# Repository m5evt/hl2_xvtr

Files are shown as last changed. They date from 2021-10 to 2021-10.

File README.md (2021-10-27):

# hl2_xvtr
hl2_xvtr

Hermes-Lite 2 transverter companion card

Designed with the same footprint as the N2ADR filter board, this companion card is to be coupled to the Hermes-Lite 2 SDR transceiver. The transverter clock is designed to be sourced from the HL2 clock outputs. Power output is around 20 dBm and an amplifier will need to be used with this. 

The design has been built and tested on both 6m and 2m.

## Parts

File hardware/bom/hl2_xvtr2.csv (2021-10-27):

ID | Value | Footprint | Quantity | Source
C25, C31 | 10uF | CP_Elec_5x5.4 | 2 | Mouser: 598-106SML035M
C8, C14, C42 | 100p | SMD-0603 | 3
C4, C10, C12, C13, C15, C17, C19, C22, C32, C33, C34, C47, C50 | 1n | SMD-0603_c | 13
C21, C30, | 3.3p | SMD-0603_c | 2
C38, C45 | 2.7p | SMD-0603_c | 2
C23, C29, | 4.7p | SMD-0603_c | 2
C41, C48 | 5.6p | SMD-0603_c | 2
C2, C5, C35 | 82p | SMD-0603_c | 3
C6, C36, C37 | 510p | SMD-0603_c | 3
C20, C49, C51 | 1u | SMD-0603_c | 3
C24, C28, C43 | 0.5p | SMD-0603_c | 3
C1, C7 | 68p | SMD-0603_c | 2
C9, C11 | 150p | SMD-0603_c | 2
C16, C18 | 47p | SMD-0603_c | 2
C3 | 560p | SMD-0603_c | 1
C26 | 7.5p | SMD-0603_c | 1
C27 | DNF | SMD-0603_c | 1
C39 | 10p | SMD-0603_c | 1
C40 | 1.2p | SMD-0603_c | 1
C44 | 3.3p | SMD-0603_c | 1
C46 | 8.2p | SMD-0603_c | 1
R13, R15, R41, R42 | 390R | SMD-0603_r | 4
R11, R36, R40 | 1k | SMD-0603_r | 3
R9, R12 | 10k | SMD-0603_r | 2
R8 | 0R | SMD-0603_r | 1
R10 | 470R | SMD-0603_r | 1
R37 | 47R | SMD-0603_r | 1
R38 | 220k | SMD-0603_r | 1
R43 | 10R | SMD-0603_r | 1
R1, R3 | 150R | SMD-0805 | 2
R2 | 38R | SMD-0805 | 1
L1, L7, L15, L16 | 470nH | SMD-0805 | 4 | Mouser: 994-0805HP-471XGRC
L2, L3, L5 | 270nH | SMD-0805 | 3 | Mouser: 994-0805HP-271XGRB
L4, L8 | 1uH | SMD-0805 | 2 | Mouser: 994-0805AF-102XJRB
L6, L9 | 220nH | SMD-0805 | 2 | Mouser: 994-0805HP-221XGRC
L18, L22 | 68nH | SMD-0805 | 2 | Mouser: 652-CW201212-68NJ
L10, L11, L12, L17, L21 | 150nH | coilcraft_tunable_coil | 5 | Mouser: 994-150-04J08L
D2, D8 | 1N4148W | D_SOD-123 | 2 | Mouser: 621-1N4148W-F
D1, D3 | BAP64 | SOT23_3 | 2 | Mouser: 771-BAP64-05-T/R
U2 | ADE-1H+ | Mini-Circuits_CD542_LandPatternPL-052 | 1 | Mouser: 139-ADE-1H
U5 | 74LVC1G04 | SOT-353_SC-70-5_Handsoldering | 1 | Mouser: 621-74LVC1G04SE-7
U1, U7 | PGA-105 | SOT-89-3_round | 2 | Mouser: 139-PGA-105
U3, U4 | SPF5189Z | SOT-89-3_round | 2 | Mouser: 772-SPF5189Z
U6 | 7805 | TO-263-2 | 1 | Mouser: 863-MC7805CD2TG
Q6, Q7 | SI2309 | SOT-23 | 2 | Mouser: 781-SI2309CDS-GE3
Q5 | BC807 | SOT-23 | 1 | Mouser: 583-BC807
J2, J3, J4, J5 | Conn_Coaxial-Connector | BNCEDGE | 4 | DNF
J10 | RCJ-041 | PhonoRcaRCJ-04x | 1 | MOUSER: 490-RCJ-041
J6 | Conn_01x20 | PinSocket_1x20_P2.54mm_Vertical | 1
J1 | Conn_Coaxial-Connector | U.FL_Hirose_U.FL-R-SMT-1_Vertical | 1 | Mouser: 712-CONUFL001-SMD-T
P1 | CONN_01X03 | PinSocket_1x03_P2.54mm_Vertical | 1

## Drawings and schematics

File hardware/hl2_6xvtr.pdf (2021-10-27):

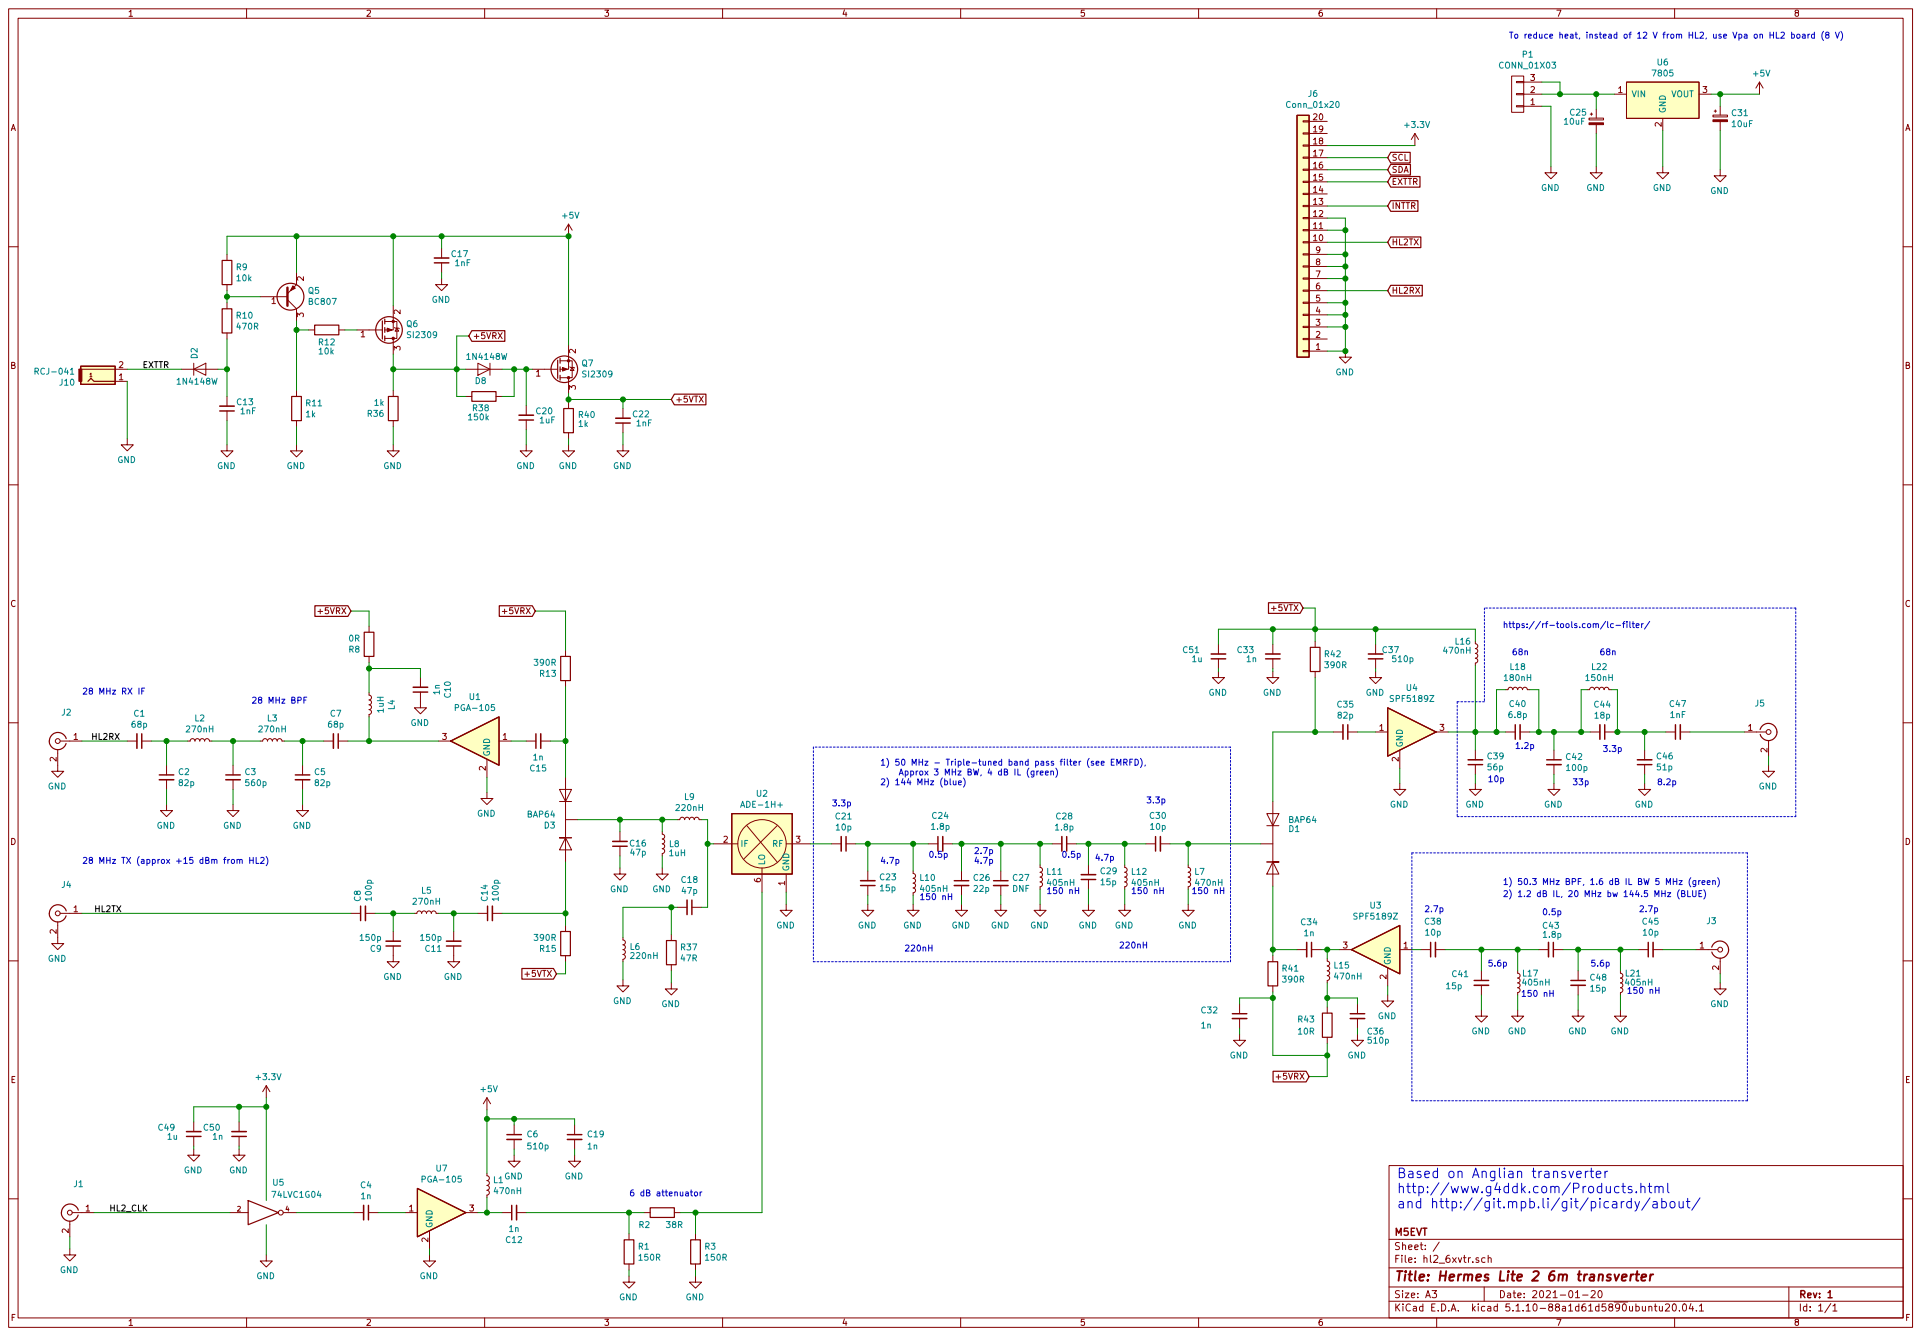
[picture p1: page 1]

To reduce heat, instead of 12 V from HL2, use Vpa on HL2 board (8 V)
J6 Conn_01x20 C51

https://rf-tools.com/lc-filter/

1) 50.3 MHz BPF, 1.6 dB IL BW 5 MHz (green) 28 MHz RX IF

1) 50 MHz - Triple-tuned band pass filter (see EMRFD),
Approx 3 MHz BW, 4 dB IL (green)
2) 144 MHz (blue)

28 MHz TX (approx +15 dBm from HL2)

2) 1.2 dB IL, 20 MHz bw 144.5 MHz (BLUE)

and http://git.mpb.li/git/picardy/about/ 150 nH

Based on Anglian transverter
http://www.g4ddk.com/Products.html

Id: 1/1 Title: Hermes Lite 2 6m transverter

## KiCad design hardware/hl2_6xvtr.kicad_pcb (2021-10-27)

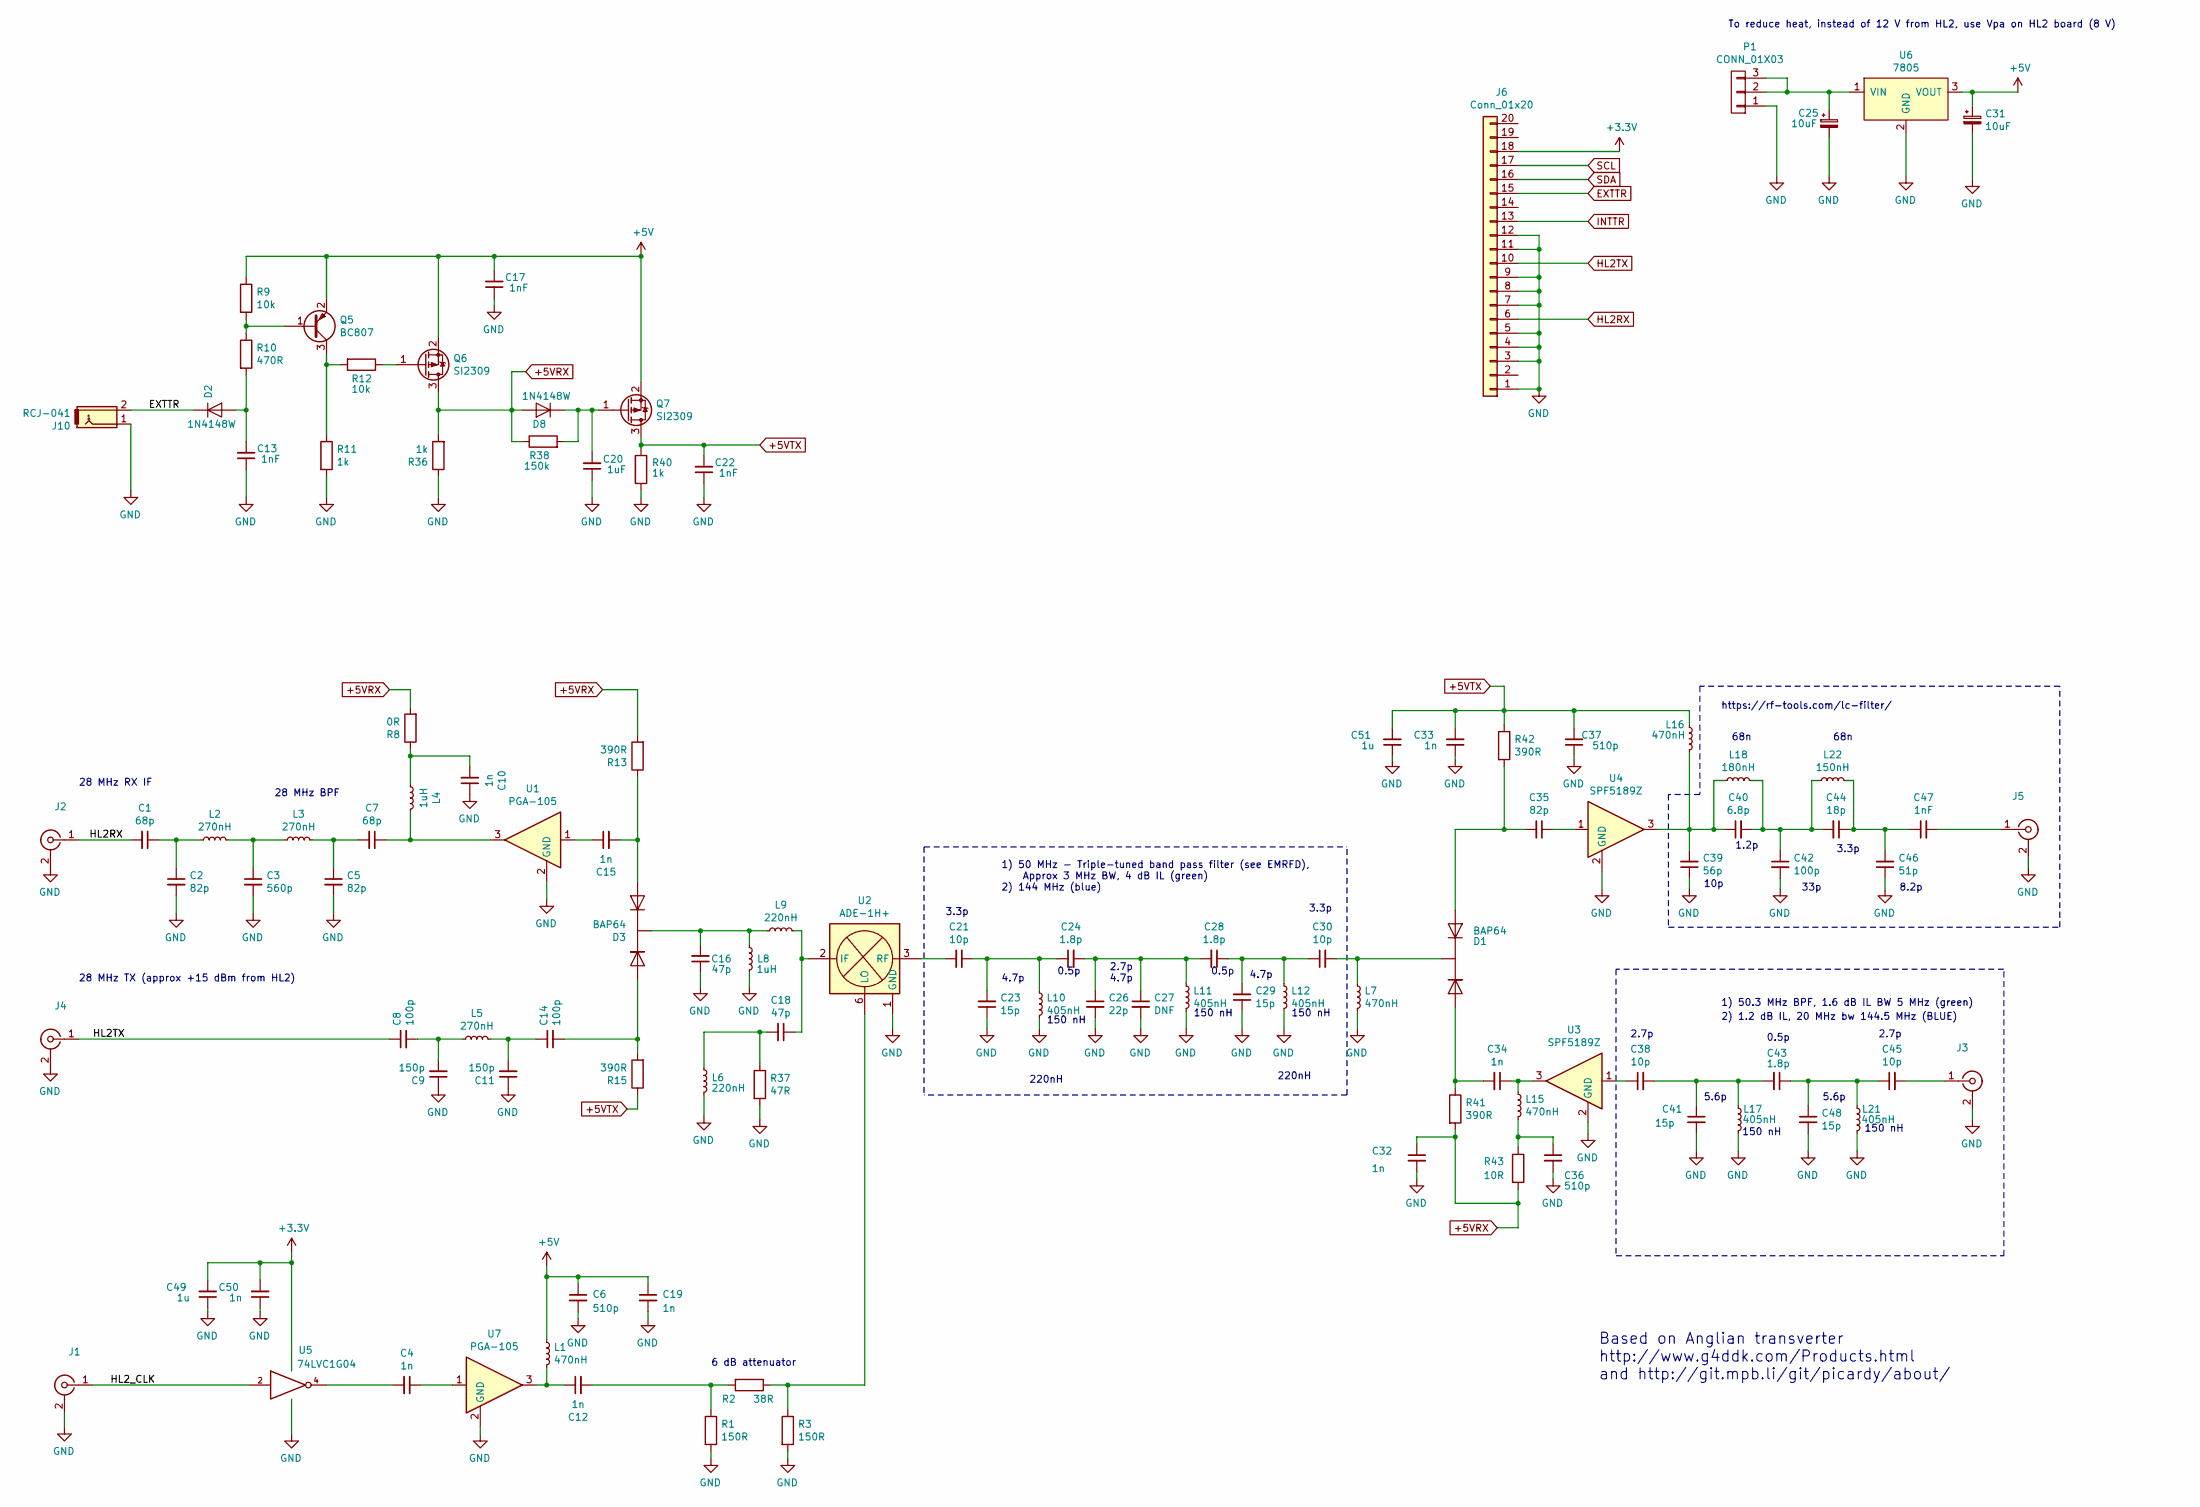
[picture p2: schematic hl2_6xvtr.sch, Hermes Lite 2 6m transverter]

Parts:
C1, C7: 68p; SMD-0603_c
C2, C5, C35: 82p; SMD-0603_c
C3: 560p; SMD-0603_c
C4, C10, C12, C15, C19, C32, C33, C34, C50: 1n; SMD-0603_c
C6, C36, C37: 510p; SMD-0603_c
C8, C14, C42: 100p; SMD-0603
C9, C11: 150p; SMD-0603_c
C13, C17, C22, C47: 1nF; SMD-0603_c
C16, C18: 47p; SMD-0603_c
C20: 1uF; SMD-0603_c
C21, C30, C38, C45: 10p; SMD-0603_c
C23, C29, C41, C48: 15p; SMD-0603_c
C24, C28, C43: 1.8p; SMD-0603_c
C25, C31: 10uF; CP_Elec_5x5.4
C26: 22p; SMD-0603_c
C27: DNF; SMD-0603_c
C39: 56p; SMD-0603_c
C40: 6.8p; SMD-0603_c
C44: 18p; SMD-0603_c
C46: 51p; SMD-0603_c
C49, C51: 1u; SMD-0603_c
D1, D3: BAP64; SOT23_3
D2, D8: 1N4148W; D_SOD-123
J1: Conn_Coaxial-Connector; U.FL_Hirose_U.FL-R-SMT-1_Vertical
J2, J3, J4, J5: Conn_Coaxial-Connector; BNCEDGE
J6: Conn_01x20; PinSocket_1x20_P2.54mm_Vertical
J10: RCJ-041; PhonoRcaRCJ-04x
L1, L7, L15, L16: 470nH; SMD-0805
L2, L3, L5: 270nH; SMD-0805
L4, L8: 1uH; SMD-0805
L6, L9: 220nH; SMD-0805
L10, L11, L12, L17, L21: 405nH; coilcraft_tunable_coil
L18: 180nH; SMD-0805
L22: 150nH; SMD-0805
P1: CONN_01X03; PinSocket_1x03_P2.54mm_Vertical
Q5: BC807; SOT-23
Q6, Q7: SI2309; SOT-23
R1, R3: 150R; SMD-0805
R2: 38R; SMD-0805
R8: 0R; SMD-0603_r
R9, R12: 10k; SMD-0603_r
R10: 470R; SMD-0603_r
R11, R36, R40: 1k; SMD-0603_r
R13, R15, R41, R42: 390R; SMD-0603_r
R37: 47R; SMD-0603_r
R38: 150k; SMD-0603_r
R43: 10R; SMD-0603_r
U1, U7: PGA-105; SOT-89-3_round
U2: ADE-1H+; Mini-Circuits_CD542_LandPatternPL-052
U3, U4: SPF5189Z; SOT-89-3_round
U5: 74LVC1G04; SOT-353_SC-70-5_Handsoldering
U6: 7805; TO-263-2

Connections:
+3V3: C49.2, C50.2, J6.18, U5.5 (VCC)
+5V: C6.1, C17.2, C19.1, C31.1, L1.1, Q5.2 (E), Q6.2 (S), Q7.2 (S), R9.1, U6.3 (VOUT)
+5VRX: C32.1, D8.2 (A), Q6.3 (D), R8.2, R13.2, R36.2, R38.1, R41.2, R43.2
+5VTX: C22.2, C33.2, C37.2, C51.2, L16.1, Q7.3 (D), R15.1, R40.1, R42.1
/HL2_CLK: J1.1 (In), U5.2
EXTTR: D2.1 (K), J6.15, J10.2
GND: C2.2, C3.2, C5.2, C6.2, C9.1, C10.1, C11.1, C13.1, C16.1, C17.1, C19.2, C20.1, C22.1, C23.1, C25.2, C26.2, C27.2, C29.1, C31.2, C32.2, C33.1, C36.2, C37.1, C39.1, C41.2, C42.2, C46.1, C48.2, C49.1, C50.1, C51.1, J1.2 (Ext), J2.2 (Ext), J3.2 (Ext), J4.2 (Ext), J5.2 (Ext), J6.1, J6.3, J6.4, J6.5, J6.7, J6.8, J6.9, J6.11, J6.12, J10.1, L6.2, L7.2, L8.2, L10.2, L11.2, L12.2, L17.1, L21.1, P1.1, R1.2, R3.2, R11.2, R36.1, R37.2, R40.2, U1.2 (GND), U2.1 (GND), U2.4 (GND), U2.5 (GND), U3.2 (GND), U4.2 (GND), U5.3 (GND), U6.2 (GND), U7.2 (GND)
HL2RX: C1.2, J2.1 (In), J6.6
HL2TX: C8.1, J4.1 (In), J6.10
INTTR: J6.13
unnamed: C1.1, C2.1, L2.1
unnamed: C3.1, L2.2, L3.1
unnamed: C4.1, U7.1
unnamed: C4.2, U5.4
unnamed: C5.1, C7.2, L3.2
unnamed: C7.1, L4.2, U1.3
unnamed: C8.2, C9.2, L5.1
unnamed: C10.2, L4.1, R8.1
unnamed: C11.2, C14.1, L5.2
unnamed: C12.1, L1.2, U7.3
unnamed: C12.2, R1.1, R2.2
unnamed: C13.2, D2.2 (A), R10.2
unnamed: C14.2, D3.1 (A), R15.2
unnamed: C15.1, U1.1
unnamed: C15.2, D3.2 (A), R13.1
unnamed: C16.2, D3.3 (K), L8.1, L9.1
unnamed: C18.1, L9.2, U2.2 (IF)
unnamed: C18.2, L6.1, R37.1
unnamed: C20.2, D8.1 (K), Q7.1 (G), R38.2
unnamed: C21.1, C23.2, C24.1, L10.1
unnamed: C21.2, U2.3 (RF)
unnamed: C24.2, C26.1, C27.1, C28.2, L11.1
unnamed: C25.1, P1.2, P1.3, U6.1 (VIN)
unnamed: C28.1, C29.2, C30.1, L12.1
unnamed: C30.2, D1.3 (K), L7.1
unnamed: C34.1, L15.1, U3.3
unnamed: C34.2, D1.1 (A), R41.1
unnamed: C35.1, U4.1
unnamed: C35.2, D1.2 (A), R42.2
unnamed: C36.1, L15.2, R43.1
unnamed: C38.1, U3.1
unnamed: C38.2, C41.1, C43.2, L17.2
unnamed: C39.2, C40.1, L16.2, L18.1, U4.3
unnamed: C40.2, C42.1, C44.2, L18.2, L22.1
unnamed: C43.1, C45.1, C48.1, L21.2
unnamed: C44.1, C46.2, C47.1, L22.2
unnamed: C45.2, J3.1 (In)
unnamed: C47.2, J5.1 (In)
unnamed: Q5.1 (B), R9.2, R10.1
unnamed: Q5.3 (C), R11.1, R12.2
unnamed: Q6.1 (G), R12.1
unnamed: R2.1, R3.1, U2.6 (LO)
SCL: J6.17
SDA: J6.16

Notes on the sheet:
Based on Anglian transverter http://www.g4ddk.com/Products.html and http://git.mpb.li/git/picardy/about/
28 MHz RX IF
28 MHz TX (approx +15 dBm from HL2)
1) 50.3 MHz BPF, 1.6 dB IL BW 5 MHz (green)
28 MHz BPF
1) 50 MHz - Triple-tuned band pass filter (see EMRFD), Approx 3 MHz BW, 4 dB IL (green) 2) 144 MHz (blue)
https://rf-tools.com/lc-filter/
To reduce heat, instead of 12 V from HL2, use Vpa on HL2 board (8 V)
6 dB attenuator
2.7p
5.6p
0.5p
150 nH
10p
33p
8.2p
3.3p
1.2p
68n
2) 1.2 dB IL, 20 MHz bw 144.5 MHz (BLUE)
2.7p 4.7p
4.7p
220nH

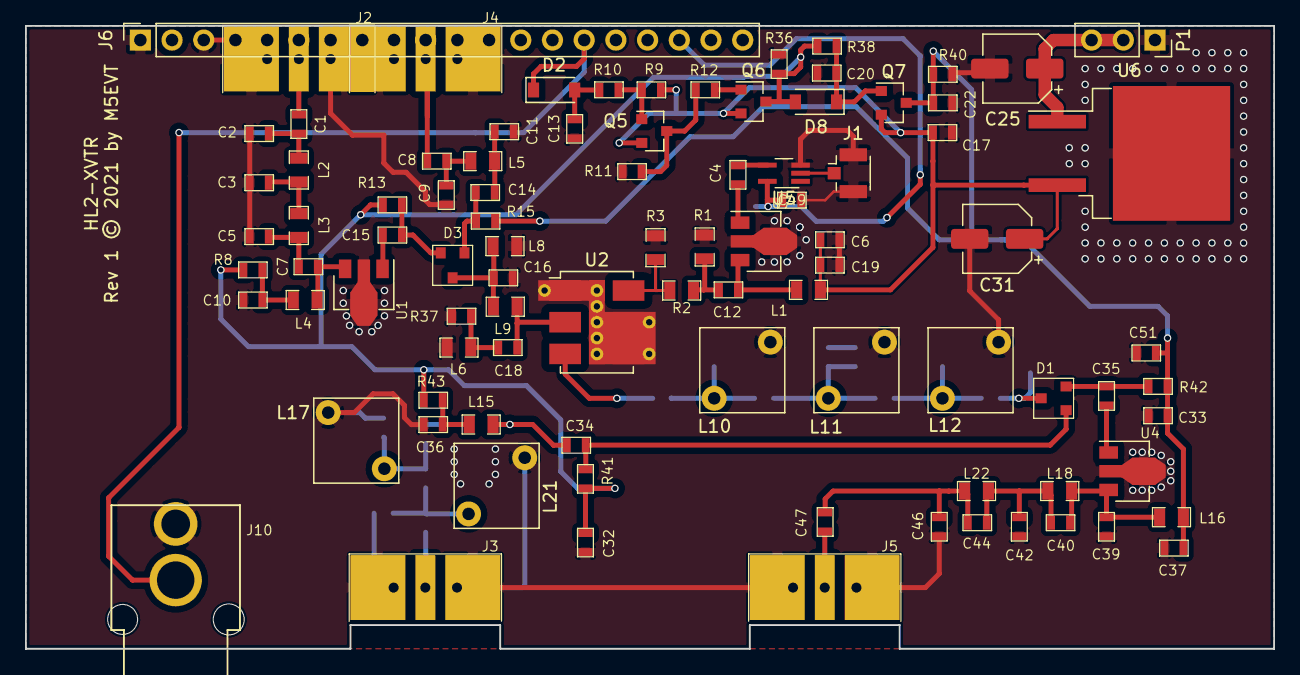
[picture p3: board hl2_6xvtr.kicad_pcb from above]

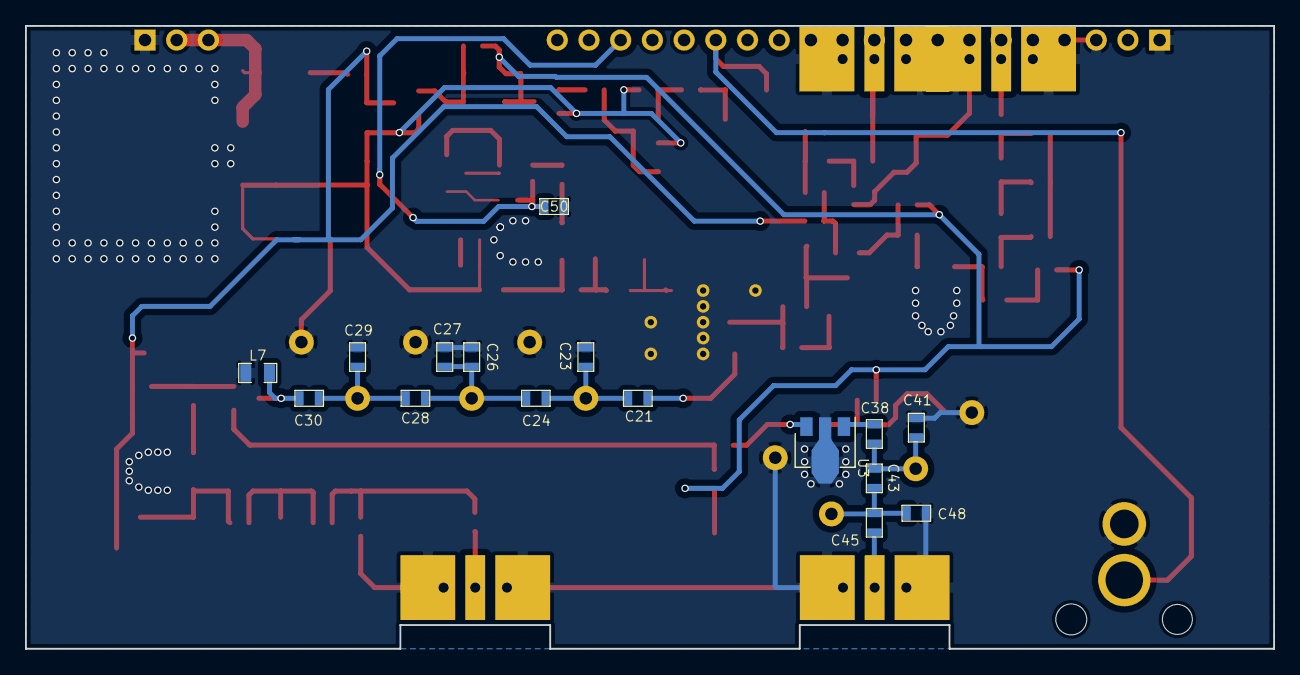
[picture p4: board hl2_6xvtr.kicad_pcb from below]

Board: 2 copper layers, 100.0 x 49.9 mm, 108 parts (16 on the bottom side), 51 nets.

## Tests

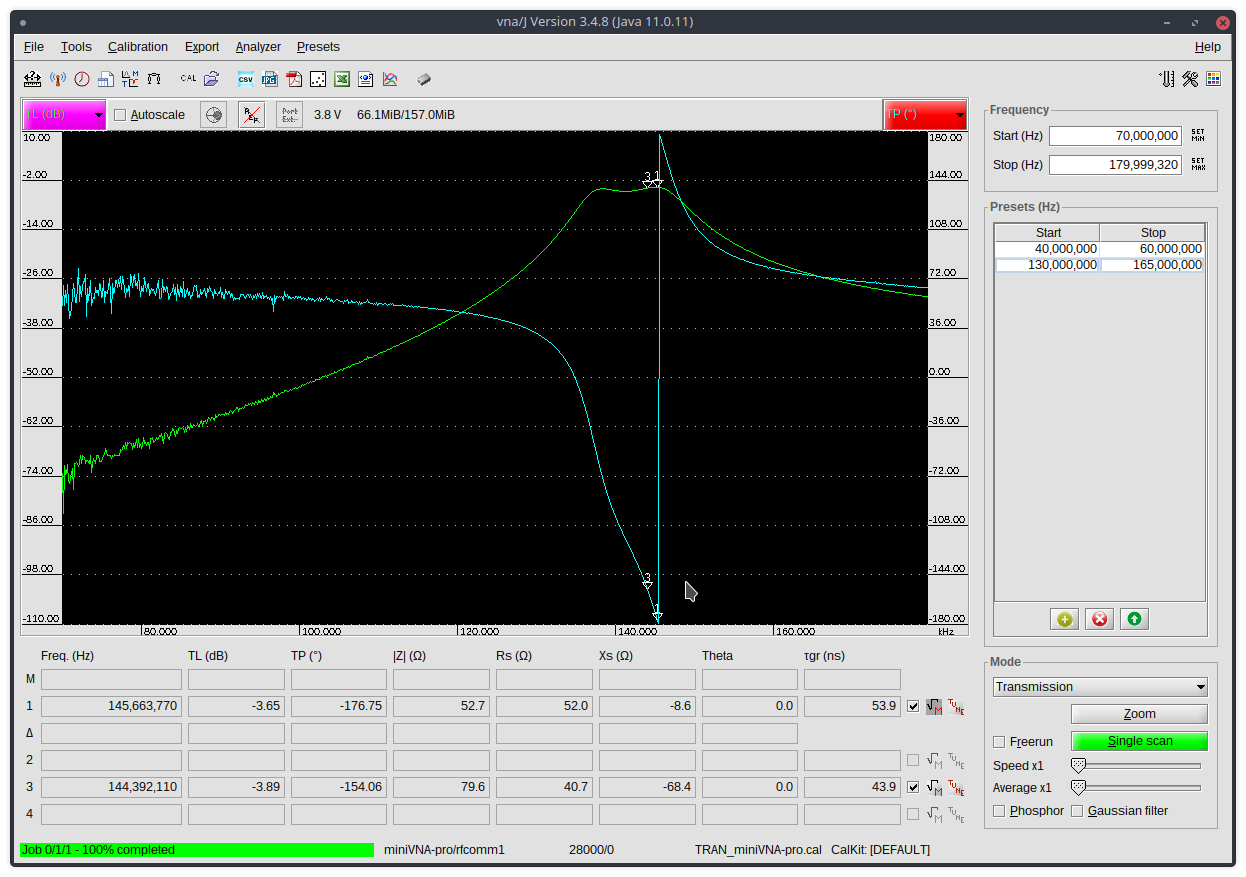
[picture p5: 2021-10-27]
measurements/2m_input_bpf.png

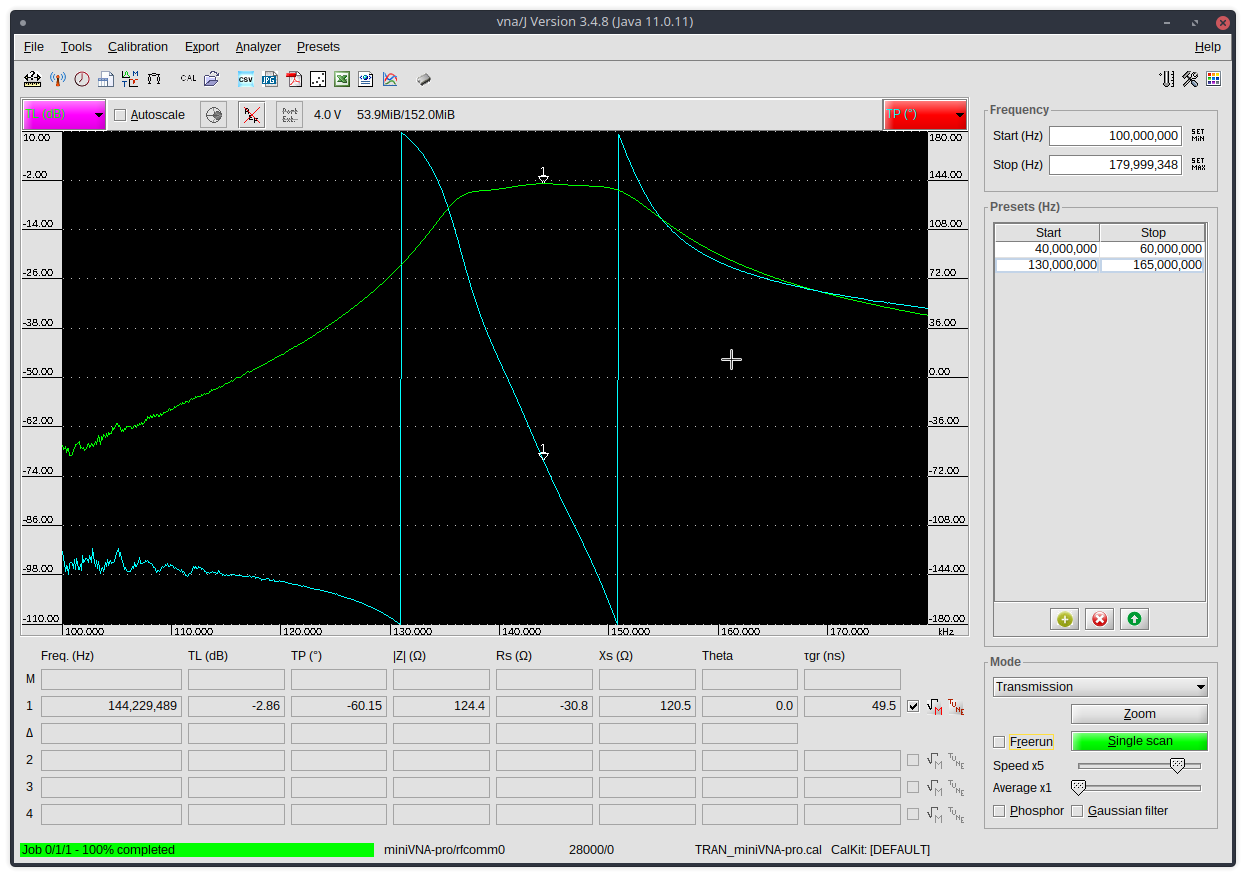
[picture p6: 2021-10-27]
measurements/2m_mixer_bpf.png

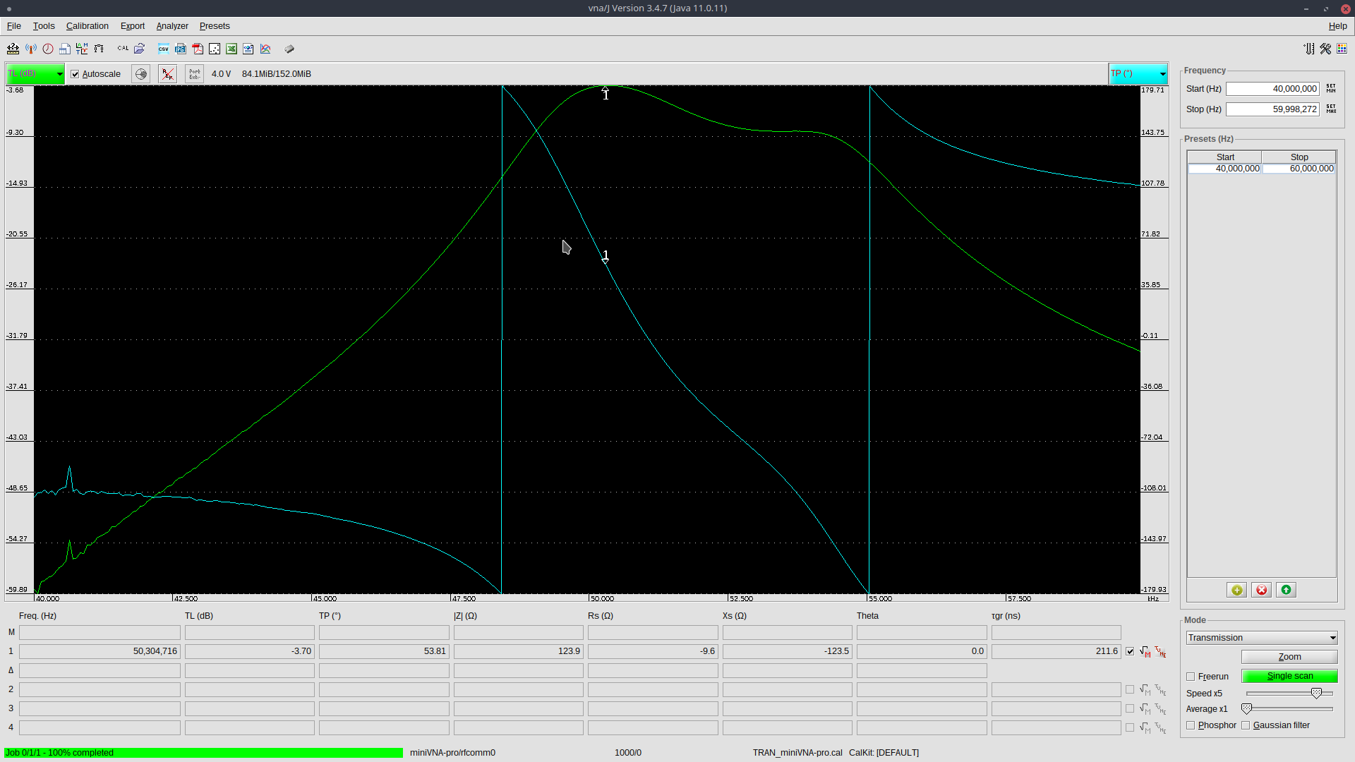
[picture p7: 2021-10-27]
measurements/6m_mixer_bpf.png

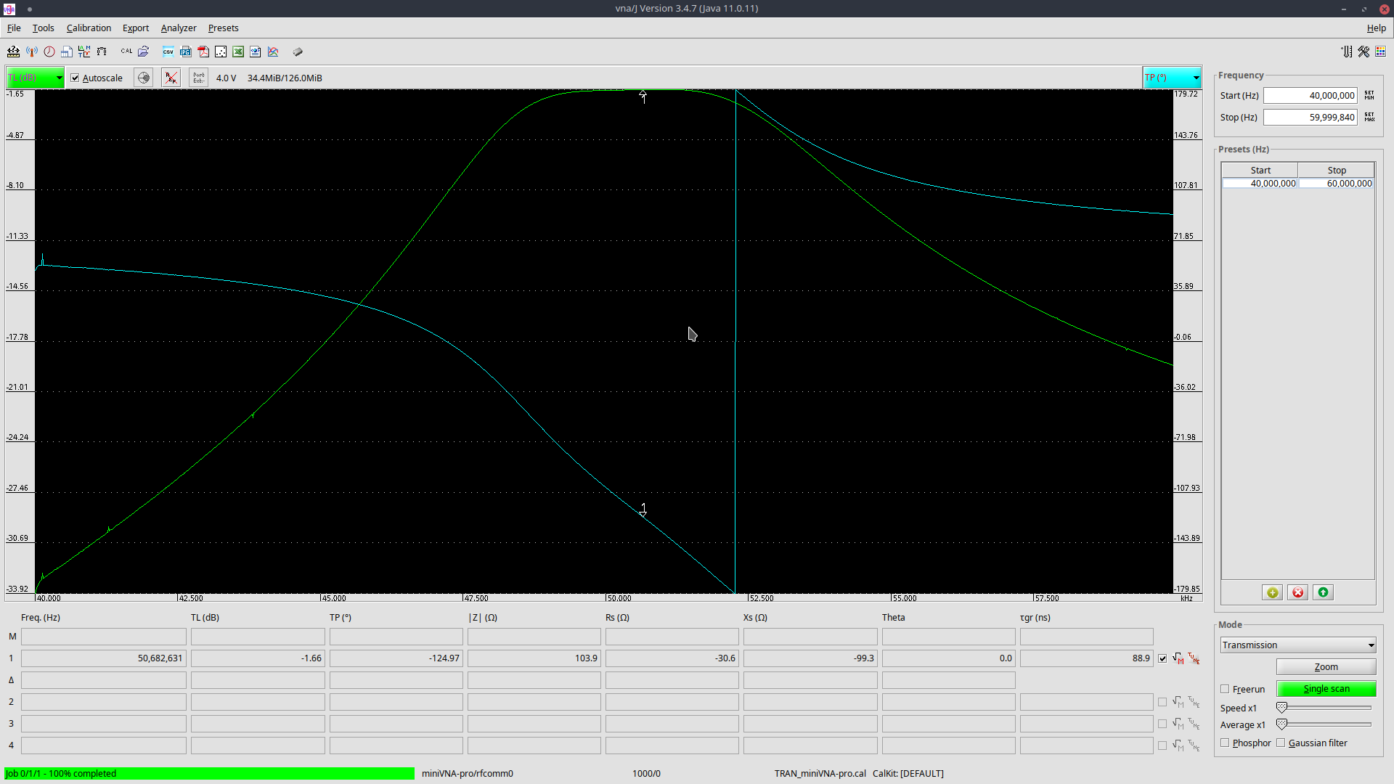
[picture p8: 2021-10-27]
measurements/6m_input_bpf.png

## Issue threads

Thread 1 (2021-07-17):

PTT should be EXTTR

m5evt, 2021-07-17:
INTTR is pulled up to 3V3 but PTT circuit on board use 5V, never pulls low enough on on TX. Removed INTTR pin from header and jumpered to EXTTR and works.

Closed 2021-09-05.

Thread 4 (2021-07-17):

HL2 CL2

m5evt, 2021-07-17:
See discussion [here](https://groups.google.com/g/hermes-lite/c/AXbcdPFGr3I/m/aRJcchlLAQAJ).

Modified board to have; 74LVC1G04SE-7 buffer -> PGA105 -> 6dB pad -> Diode mixer.

Measure 19.2 dBm in 50 R load (with no mixer connected). Mixer datasheet quotes "Maximum ratings: RF Power 200mW". Assume this covers LO too.

Closed 2021-09-05.

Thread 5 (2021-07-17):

Thermal vias around Vreg and MMICs

m5evt, 2021-07-17:
Temperatures on the board are not excessive (measure around 50 deg C on Vreg). But thermal vias around high current components would be beneficial.

Closed 2021-09-05.

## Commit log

2021-09-05 Fixes #6, #2, partial #1, #4
    [hl2_6xvtr.sch]
2021-09-05 R2 schem, PCB and gerbers
    Fixes #1, fixes #4, fixes #5
    [hl2_6xvtr-B_Cu.gbr, hl2_6xvtr-B_Mask.gbr, hl2_6xvtr-B_Paste.gbr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]
2021-09-05 Fix gerber zip
2021-10-27 Add 2m component values to schematic and BoM
    [hl2_6xvtr.csv, hl2_6xvtr.kicad_pcb, hl2_6xvtr.sch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]

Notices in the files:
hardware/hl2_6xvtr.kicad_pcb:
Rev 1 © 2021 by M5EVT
